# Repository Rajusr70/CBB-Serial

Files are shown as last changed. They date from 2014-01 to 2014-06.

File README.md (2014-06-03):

CBB-Serial
==========

This repository contains the design files for the Logic Supply CBB-Serial Cape for the 
BeagleBone and BeagleBone Black. It adds RS232, RS485 and CAN communication capabilities
to the BeagleBone.

The CBB-Serial Cape is available at http://www.logicsupply.com/components/beaglebone/capes/cbb-serial/

Check out the CBB-Serial manual at https://docs.google.com/document/d/1y0aKYqKd3_5HuzUvIepQmC5AjbFIqBlBak-Jtv0YB7Q/edit?usp=sharing

----

Follow us on Google+ for updates and more information: https://plus.google.com/u/0/b/103613886667848850929/

Created by Alexander Hiam for Logic Supply.

This work is licensed under the Creative Commons Attribution-Share Alike 3.0 Unported License. 
To view a copy of this license, visit http://creativecommons.org/licenses/by-sa/3.0/ or send a 
letter to Creative Commons, 171 Second Street, Suite 300, San Francisco, California, 94105, USA.

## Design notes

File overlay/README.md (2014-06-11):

CBB-Serial Device Tree Overlay
==============================

`CBB-Serial-00A0.dts` is the uncompiled device tree overlay for the
CBB-Serial cape (currently working but not quite complete). 

To install the overlay, first compile it:

```
 # dtc -O dtb -o CBB-Serial-00A0.dtbo -b 0 -@ CBB-Serial-00A0.dts
```

Then add it to the overlay directory:

```
 # mv CBB-Serial-00A0.dtbo /lib/firmware
```

It will then be loaded automatically by the cape manager the next time
the BeagleBone boots with the CBB_Serial EEPROM attached. It can also
be loaded manually:

```
 # echo CBB-Serial > /sys/devices/bone_capemgr.*/slots
```

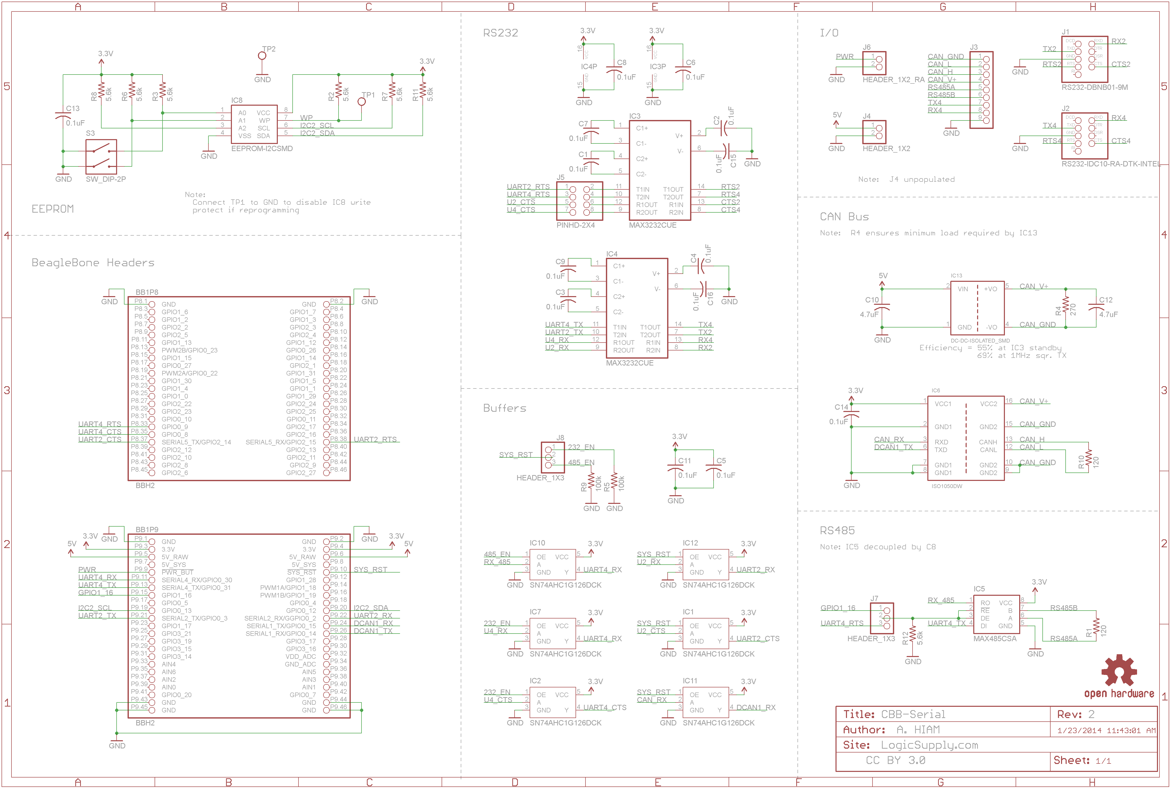
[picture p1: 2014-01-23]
CBB-Serial-sch.png

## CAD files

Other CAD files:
SketchUp-model/CBB-Serial-r02.skp

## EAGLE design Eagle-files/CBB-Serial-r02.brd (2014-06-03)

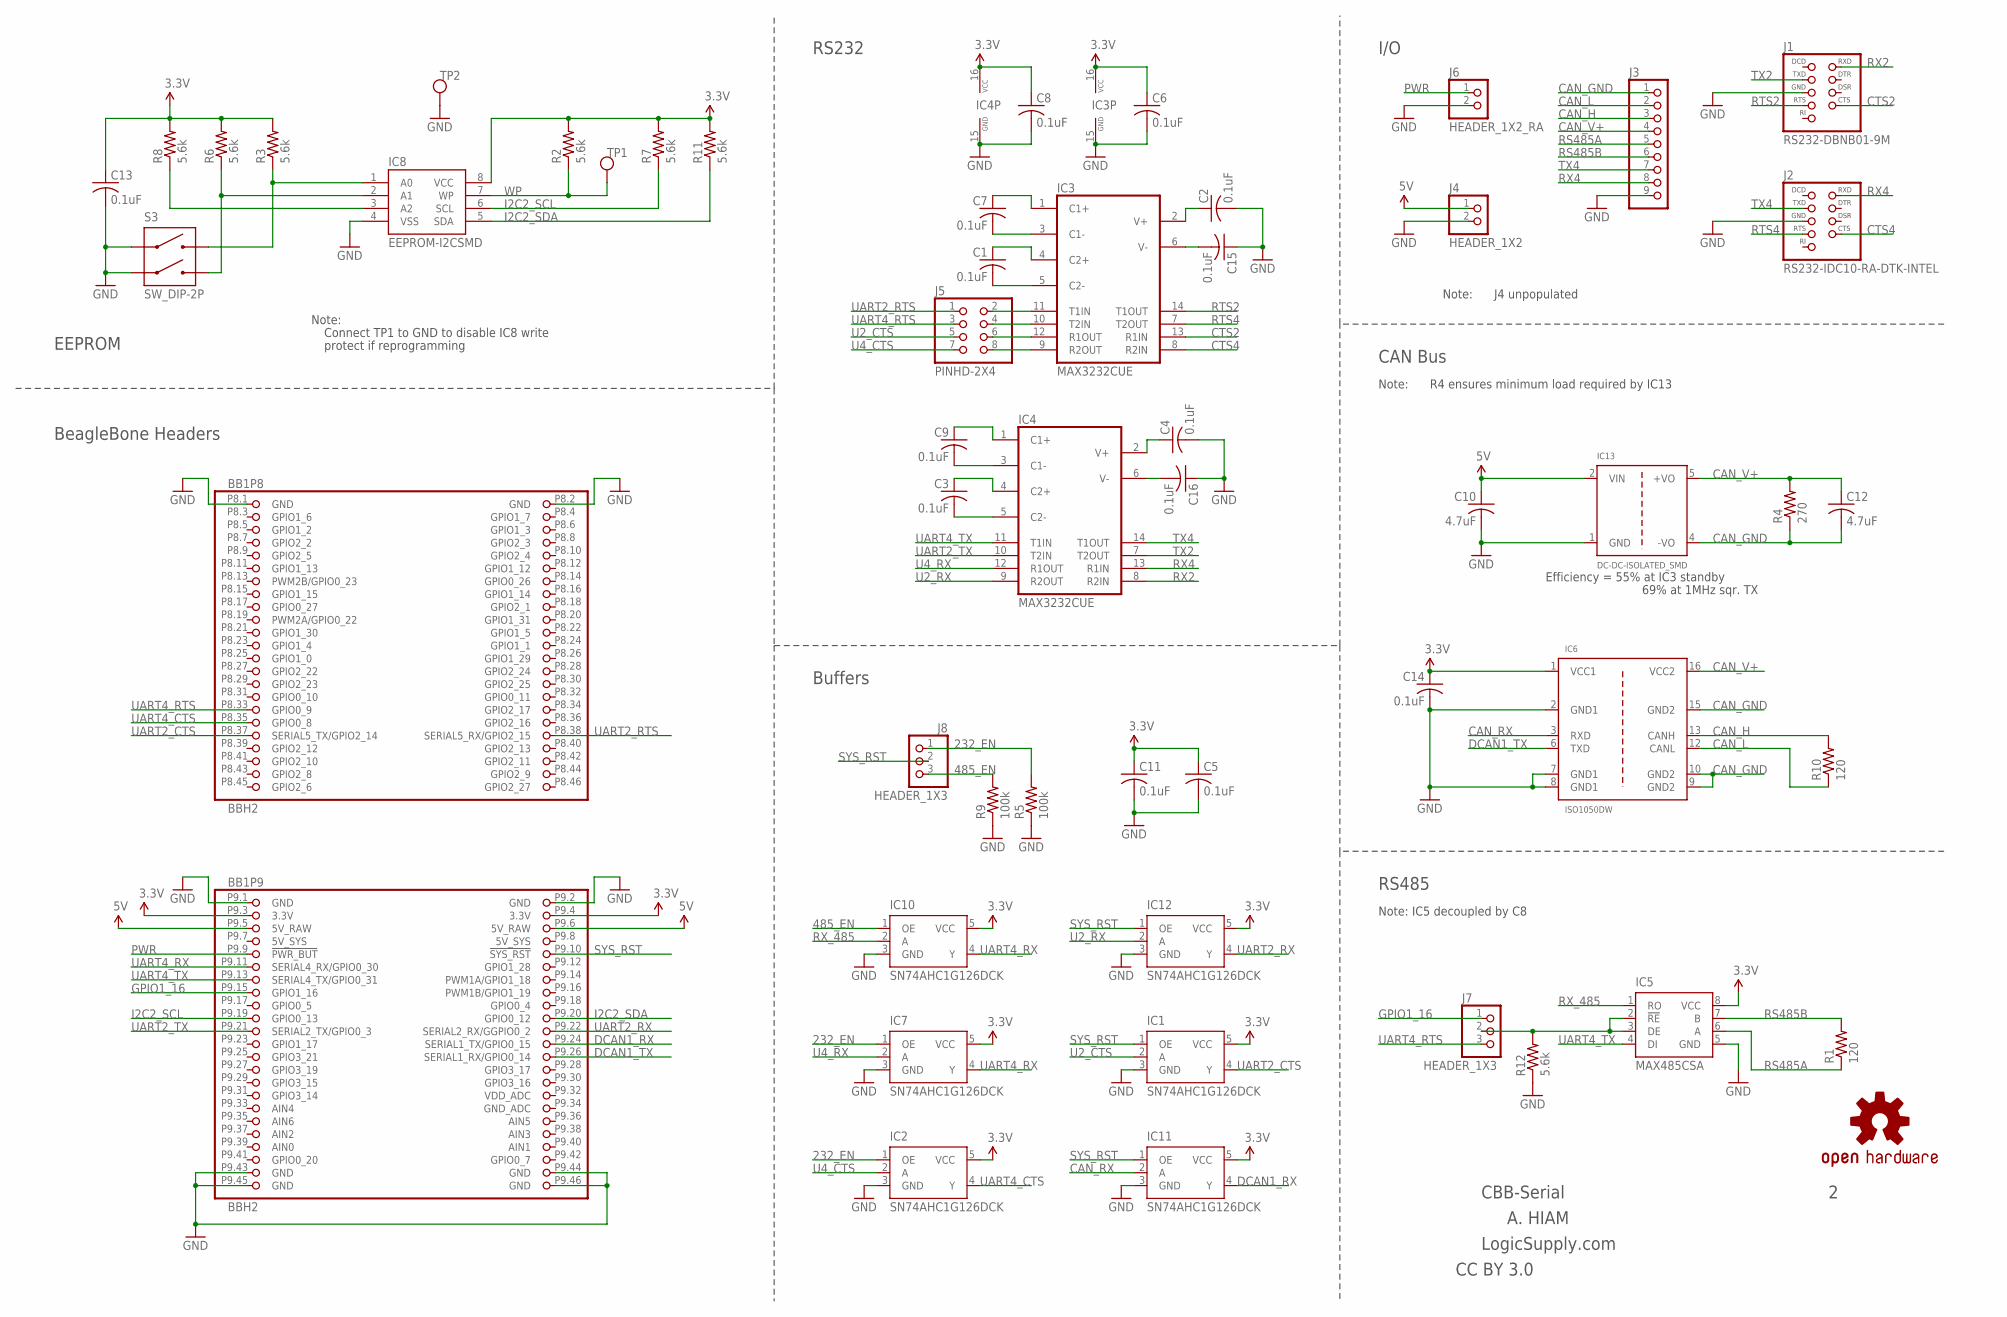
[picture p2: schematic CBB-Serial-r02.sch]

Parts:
BB1: BBH2; BB_CAPE_TOP
C1, C2, C3, C4, C5, C6, C7, C8, C9, C11, C13, C14, C15, C16: 0.1uF; C0603
C10, C12: 4.7uF; C0805
IC1, IC2, IC7, IC10, IC11, IC12: SN74AHC1G126DCK; DCK-R-PDSO-G5
IC3, IC4: MAX3232CUE; TSSOP16; MPN MAX3232CUE+
IC5: MAX485CSA; SO08
IC6: ISO1050DW; SO16W
IC8: EEPROM-I2CSMD; SO08
IC13: DC-DC-ISOLATED_SMD; DC-DC-SMD
J1: RS232-DBNB01-9M; DB9-DBNB01-9M
J2: RS232-IDC10-RA-DTK-INTEL; HEADER_2X5-SHROUDED-RA
J3: SCREWTERM_9PIN_2-54; SCREWTERM_1725724_9
J4: HEADER_1X2
J5: PINHD-2X4; HEADER_2X4
J6: HEADER_1X2_RA
J7, J8: HEADER_1X3
R1, R10: 120; R1206
R2, R3, R6, R7, R8, R11, R12: 5.6k; R0603
R4: 270; R1206
R5, R9: 100k; R0603
S3: SW_DIP-2P; DIPSWITCH-2P-SMD-1.27
TP1, TP2: TEST_POINT_PTH
U$7: OSHW-LOGOM; OSHW-LOGO-M

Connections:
3.3V: BB1.P9.3 (3.3V), BB1.P9.4 (3.3V), C5.1, C6.1, C8.1, C11.1, C13.1, C14.1, IC1.5 (VCC), IC2.5 (VCC), IC3.16 (VCC), IC4.16 (VCC), IC5.8 (VCC), IC6.1 (VCC1), IC7.5 (VCC), IC8.8 (VCC), IC10.5 (VCC), IC11.5 (VCC), IC12.5 (VCC), R2.2, R3.2, R6.2, R7.2, R8.2, R11.2
5V: BB1.P9.5 (5V_RAW), BB1.P9.6 (5V_RAW), C10.1, IC13.2 (VIN), J4.1
5V_SYS: BB1.P9.7 (5V_SYS), BB1.P9.8 (5V_SYS)
232_EN: IC2.1 (OE), IC7.1 (OE), J8.1, R5.2
485_EN: IC10.1 (OE), J8.3, R9.2
CAN_GND: C12.2, IC6.9 (GND2), IC6.10 (GND2), IC6.15 (GND2), IC13.4 (-VO), J3.1, R4.1
CAN_H: IC6.13 (CANH), J3.3, R10.2
CAN_L: IC6.12 (CANL), J3.2, R10.1
CAN_RX: IC6.3 (RXD), IC11.2 (A)
CAN_V+: C12.1, IC6.16 (VCC2), IC13.5 (+VO), J3.4, R4.2
CTS2: IC3.13 (R1IN), J1.8 (CTS)
CTS4: IC3.8 (R2IN), J2.6 (CTS)
DCAN1_RX: BB1.P9.24 (SERIAL1_TX/GPIO0_15), IC11.4 (Y)
DCAN1_TX: BB1.P9.26 (SERIAL1_RX/GPIO0_14), IC6.6 (TXD)
GND: BB1.P8.1 (GND), BB1.P8.2 (GND), BB1.P9.1 (GND), BB1.P9.2 (GND), BB1.P9.43 (GND), BB1.P9.44 (GND), BB1.P9.45 (GND), BB1.P9.46 (GND), C2.2, C4.2, C5.2, C6.2, C8.2, C10.2, C11.2, C13.2, C14.2, C15.1, C16.1, IC1.3 (GND), IC2.3 (GND), IC3.15 (GND), IC4.15 (GND), IC5.5 (GND), IC6.2 (GND1), IC6.7 (GND1), IC6.8 (GND1), IC7.3 (GND), IC8.4 (VSS), IC10.3 (GND), IC11.3 (GND), IC12.3 (GND), IC13.1 (GND), J1.5 (GND), J2.9 (GND), J3.9, J4.2, J6.2, R5.1, R9.1, R12.1, S3.1A, S3.2A, TP2.P$1
GPIO1_16: BB1.P9.15 (GPIO1_16), J7.1
I2C2_SCL: BB1.P9.19 (GPIO0_13), IC8.6 (SCL), R7.1
I2C2_SDA: BB1.P9.20 (GPIO0_12), IC8.5 (SDA), R11.1
unnamed: C9.2, IC4.3 (C1-)
unnamed: C3.2, IC4.5 (C2-)
unnamed: C9.1, IC4.1 (C1+)
unnamed: C3.1, IC4.4 (C2+)
unnamed: C16.2, IC4.6 (V-)
unnamed: C4.1, IC4.2 (V+)
unnamed: C15.2, IC3.6 (V-)
unnamed: C7.2, IC3.3 (C1-)
unnamed: IC5.2 (!RE), IC5.3 (DE), J7.2, R12.2
unnamed: C1.2, IC3.5 (C2-)
unnamed: C7.1, IC3.1 (C1+)
unnamed: C1.1, IC3.4 (C2+)
unnamed: IC8.1 (A0), R3.1, S3.1B
unnamed: IC8.2 (A1), R6.1, S3.2B
unnamed: IC8.3 (A2), R8.1
unnamed: C2.1, IC3.2 (V+)
unnamed: IC3.11 (T1IN), J5.2
unnamed: IC3.12 (R1OUT), J5.6
unnamed: IC3.10 (T2IN), J5.4
unnamed: IC3.9 (R2OUT), J5.8
PWR: BB1.P9.9 (!PWR_BUT), J6.1
RS485A: IC5.6 (A), J3.5, R1.1
RS485B: IC5.7 (B), J3.6, R1.2
RTS2: IC3.14 (T1OUT), J1.7 (RTS)
RTS4: IC3.7 (T2OUT), J2.4 (RTS)
RX2: IC4.8 (R2IN), J1.2 (RXD)
RX4: IC4.13 (R1IN), J2.3 (RXD), J3.8
RX_485: IC5.1 (RO), IC10.2 (A)
SYS_RST: BB1.P9.10 (!SYS_RST), IC1.1 (OE), IC11.1 (OE), IC12.1 (OE), J8.2
TX2: IC4.7 (T2OUT), J1.3 (TXD)
TX4: IC4.14 (T1OUT), J2.5 (TXD), J3.7
U2_CTS: IC1.2 (A), J5.5
U2_RX: IC4.9 (R2OUT), IC12.2 (A)
U4_CTS: IC2.2 (A), J5.7
U4_RX: IC4.12 (R1OUT), IC7.2 (A)
UART2_CTS: BB1.P8.37 (SERIAL5_TX/GPIO2_14), IC1.4 (Y)
UART2_RTS: BB1.P8.38 (SERIAL5_RX/GPIO2_15), J5.1
UART2_RX: BB1.P9.22 (SERIAL2_RX/GGPIO0_2), IC12.4 (Y)
UART2_TX: BB1.P9.21 (SERIAL2_TX/GPIO0_3), IC4.10 (T2IN)
UART4_CTS: BB1.P8.35 (GPIO0_8), IC2.4 (Y)
UART4_RTS: BB1.P8.33 (GPIO0_9), J5.3, J7.3
UART4_RX: BB1.P9.11 (SERIAL4_RX/GPIO0_30), IC7.4 (Y), IC10.4 (Y)
UART4_TX: BB1.P9.13 (SERIAL4_TX/GPIO0_31), IC4.11 (T1IN), IC5.4 (DI)
WP: IC8.7 (WP), R2.1, TP1.P$1

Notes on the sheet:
CBB-Serial
A. HIAM
EEPROM
BeagleBone Headers
RS485
I/O
CAN Bus
RS232
LogicSupply.com
R4 ensures minimum load required by IC13
Efficiency = 55% at IC3 standby
69% at 1MHz sqr. TX
Buffers
Note: IC5 decoupled by C8
Note:
Connect TP1 to GND to disable IC8 write
protect if reprogramming
J4 unpopulated
CC BY 3.0

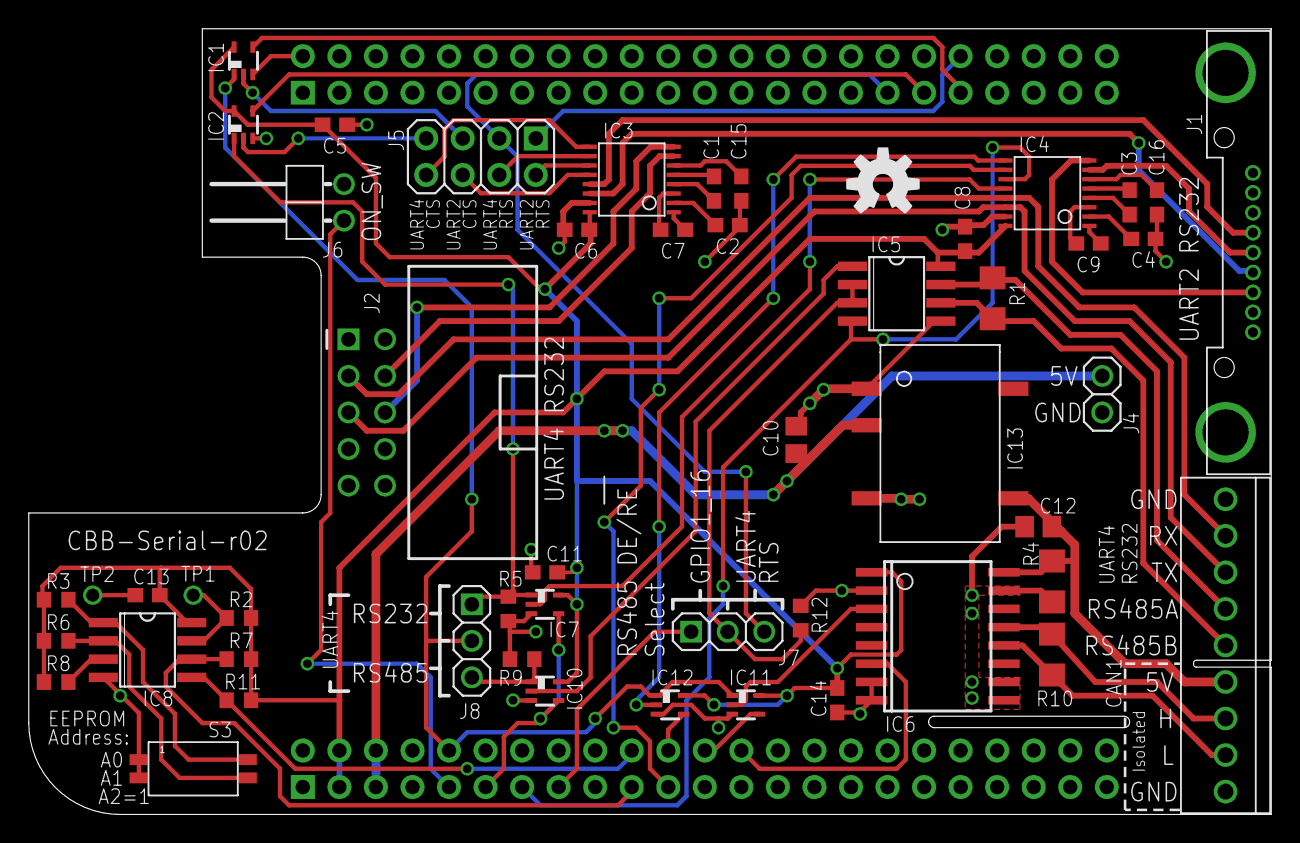
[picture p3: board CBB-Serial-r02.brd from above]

Board: 2 copper layers, 86.4 x 54.6 mm, 53 parts (1 on the bottom side), 62 nets.

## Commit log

2014-01-23 added README and schematic
2014-01-23 update to r02 schematic
2014-06-03 added Eagle files
    [CBB-Serial-r02.brd, CBB-Serial-r02.sch]
2014-07-15 added SketchUp model
    [CBB-Serial-r02.skp]

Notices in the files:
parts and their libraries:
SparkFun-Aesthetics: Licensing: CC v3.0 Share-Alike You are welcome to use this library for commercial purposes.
